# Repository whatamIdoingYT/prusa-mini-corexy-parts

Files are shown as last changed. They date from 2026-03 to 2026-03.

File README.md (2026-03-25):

# prusa-mini-corexy-parts
Additional parts for building the Prusa Mini CoreXY by SE from Printables.

The parts that you can find in this repository were designed and used by myself to build the awesome Prusa Mini CoreXY by SE from Printables. 

You can find the project here on Printables: https://www.printables.com/model/681983-prusa-mini-corexy

Make sure to check the original parts, as well as the comment section, where some people just revealed their builds and additional parts first and maybe do some measurements as well in the slicer and check the parts for errors. Maybe I've mistaken something...

For me, some parts like the X carriage shroud caused problems in the slicer, cause the walls were apparently to thin, some were to weak... Doesn't neccessarily mean, it's the same for you.

In case you have the same problems like I do, the parts attached in this repo replace the originally from SE provided parts for building the printer - those are the parts I've used for building my printer, which you can see in this video: 

You can find all the parts in the 'assets' - folder.

There is a folder called 'SpacerShims' in the 'assets' - folder. You can find various spacers and shims there. They are being used to position and hold the idlers in the Y carriages. Honestly, I forgot, which ones I've used. Just print all of them, its really just a few grams and see, what fits best for you. Maybe in the future I will do an assembly video, then I can definitely tell you, which ones I've used and in general, how the whole printer is being assembled, since there are no instructions at all. 

If I see some people interested in this project, I will do an assembly video for a basic / minimal but functional setup for a low budget of the printer.

Parts I've created / repaired / optimized are:

- X carriage (don't remember exactly what I've changed - I think I just made the middle part more stable to not crack under the pulling forces of the belts)

- fan mount for toolhead (so the fan is mounted more stable)

- X carriage shroud (original one's walls were too thin to be printed)

- front idler right (made it more rigid)

I also created some 'reinforcements' for the printer to stabilize the frame. You can see it in the video. Those parts are neccessary for one of these reinforcements:

- tower part up
- tower part down
- DiffPlate

The way the reinforcements work:

You can simply print the upper and lower part and one diff plate. The 'DiffPlate' will be layed between the upper and lower part an can be adjusted in thickness by scaling it up and down. You will want to print it in a few thicknesses to check out how thick the plate needs to be for your printer. It may vary a little bit to mine, but mine was 1.4 mm thick. By adjusting the thickness you can get the optimal support in strength for your frame. 

## **My recommended setup for you** - get yourself these parts:

- 1x 3030 extrusion 300 mm (bottom front horizontal)
- 3x 3030 extrusion 240 mm (bottom sides horizontal and one upper back horizontal)
- 2x 3030 extrusion 285 mm (bottom front vertical)
- 2x 3030 extrusion 320 mm (bottom back vertical)

- 8 idlers GT2 20 teeth 5mm bore (no teeth) for 6mm belt

- 2x around 1100mm GT2 belt 6mm (maybe just get 5m, in case you mess up some measurements and I would strongly recommend quality ones with fibreglass)

- 100 pcs of M3 x 8mm cylinder screws

You will also need to drill a 5mm hole and cut a m6 thread with a tap in the Long 320mm 3030 extrusions to mount the motors left and Right on top. At least that's how I did it and it works.

All the other parts (screws, pulleys, motors, rods, fans...) are being reused from your Prusa Mini / Mini +, so disassemble it carefully. Read trhough the project on Printables carefully. Maybe a few times. Look at all the parts in the project. I can recommend to print a lot of the 'ALU 90' ninety degree connector parts to connect every 3030 extrusion from every side you can with the other 3030 extrusions, to make the frame really rigid. It will be! You can use the 'ALU nut M3' for it as well, to secure them on the 3030 extrusions. They work fine. Make sure to maybe scale them a little bit smaller, because they can be quite hard to be inserted into the extrusions otherwise - just print one in 100 percent scale and check, if adjustments are needed for you.

Feel free to ask questions. I will try to answer them - either here, or on Printables. On Printables you will probably get more support, because it's the projects origin :)

## My personal printer config for OrcaSlicer with profiles for ESUN PETG HS and PLA+

**Important Note:** This configuration is specifically tuned for a setup with a **Bondtech bowden extruder** and a **titanium heatbreak**. If you are running a stock setup, please make sure to adjust or remove the custom E-steps (`M92`) and PID tuning values (`M301`) in the Start G-Code! I am also using a Bondtech 0.4 CHT Nozzle, so I am able to extrude a lot more filament withthe stock hotend - around twice as much as with a stock nozzle. Another thing to watch out for is the build plate position! My build plate has a space of 36mm to the left horizontal 3030 extrusion and 14mm to the right horizontal 3030 extrusion (measured from the edge of the original smooth build plate to the inner edge of the extrusions where the Y carriages are running above - horizontally measured). The flow values, as well as the pressure advance values may vary for your type of filament. I tested them for the 0.4 CHT nozzle from Bondtech and the specific filaments.

You can download my OrcaSlicer configuration from the 'printer configuration' folder. I mainly use the printer for ESUN PETG HS and for that the configuration works just fine! The ESUN PLA+ configuration also worked fine as far as I remember. Haven't been printing it for a while. The Benchy configuration should be a pretty fast speed one which I can not recommend to run. The cooling can not keep up with the printing speed. Otherwise the results weren't even that bad :) Maybe with a different duct (maybe the one from the Printables comment section) will lead to better results - looking forward for testing it!

Just download it, mess around with it and tweak it for your personal preferences! Maybe its just a good starting point for you, if you like :) Or just create your own configuration from scratch. Using the Bambu A1 Mini configuration to configurate the Prusa Mini CoreXY was the way to go for me!

## Input Shaping

I've set my input shaping values as the following for the Mini CoreXY, based on my testing,**but the Values may vary for you:**

**Filter:**

**MVZ** on **both axes**

**Frequencies:**

**37** on the **X - axis**

**40** on the **Y - axis**

## StealthChop (aka make my printer scream for dear life)

If you are not using my OrcaSlicer printer configuration and you want to print above certain speeds (probably around 75 mm/s upwards), your printer will eventually start to scream! To prevent it from doing that, turn off StealthChop on all axis with this command:

```gcode
M569 S0 X Y Z;
```
Disable directly AFTER the homing routine! It needs it for homing! Otherwise the toolhead may crash and will kill your belt by running into the Y carriage (don't ask me how I know...).
StealthChop is  being used to make your printer more silent - which apparently doesn't seem to work for this modified version of the Prusa Mini. So turn it off and use SpreadCycle instead. It's not worse - it's actually performing better. It is more noisy though compared to StealthChop (under normal circumstances), but in this case it will make your printer not scream beyond speeds of around 75 mm/s... so take the little bit more noise :)

## **Disclaimer and Limitation of Liability**

**Please read this disclaimer carefully before using, modifying, or building upon this open-source project.**

By accessing, downloading, or using the files, instructions, and information provided in this project, you agree to the following terms:

* **Assumption of Risk ("Do It At Your Own Risk"):** Building, modifying, and operating 3D printers involves **inherent risks**. You will be working with **high-voltage electricity**, **high temperatures** (hotends, heated beds), and **moving mechanical parts**. You acknowledge that you are undertaking this project **entirely at your own risk**. It is your responsibility to ensure you have the necessary skills, knowledge, and safety precautions in place before starting.

* **"As Is" Content / No Warranty:** All files, code, models, and documentation are provided **"AS IS"**, without warranty of any kind, express or implied. The creator makes **no guarantees** regarding the safety, reliability, accuracy, or suitability of this project for any specific purpose.

* **Limitation of Liability:** Under **no circumstances** shall the creator(s), contributors, or maintainers of this project be held liable for any direct, indirect, incidental, special, or consequential damages. This includes, but is **not limited to**:
    * **Personal injury or death**
    * **Property damage** (including **fire** caused by thermal runaway or electrical faults)
    * **Damage to your 3D printer** or other equipment
    * **Loss of time, materials, or profits**
    arising out of the use, inability to use, or modifications made to this project.

* **Safety Warning:** Always follow basic electrical and fire safety guidelines. **Never leave a modified or DIY 3D printer running unattended** unless you have thoroughly tested all safety features (such as thermal runaway protection, proper grounding, and appropriate wire gauges). You are **solely responsible** for ensuring your build complies with local safety regulations and standards.

**By using this project, you accept full responsibility for your actions and any outcomes that may result.**

## Acknowledgements / Credits

This project is a remix of / based on:
* **"Prusa MINI coreXY"** by SE. 
    * Source: (https://www.printables.com/model/681983-prusa-mini-corexy)
    * License: [CC BY-SA 4.0](https://creativecommons.org/licenses/by-sa/4.0/)

## License

In accordance with the ShareAlike condition of the original project and to support the open-source community, this entire project (including the newly added parts I designed) is also released under the **Creative Commons Attribution-ShareAlike 4.0 International (CC BY-SA 4.0)** license.

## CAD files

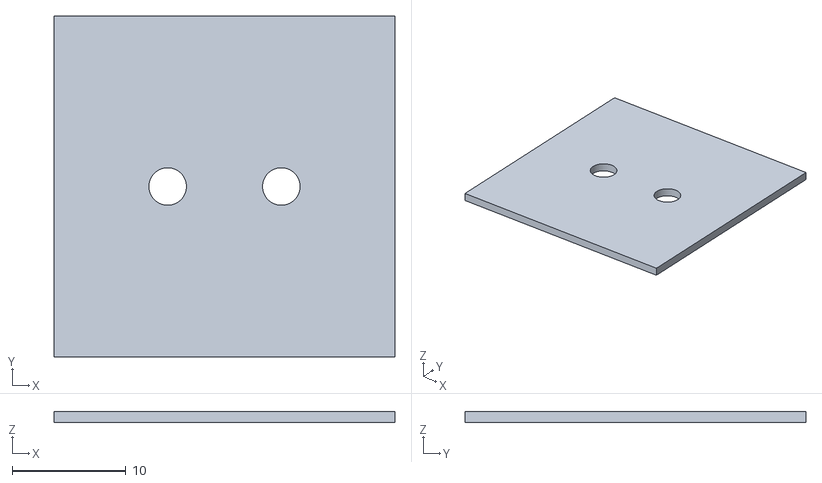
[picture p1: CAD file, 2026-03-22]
assets/DiffPlate.stl
30.0 x 30.0 x 1.00

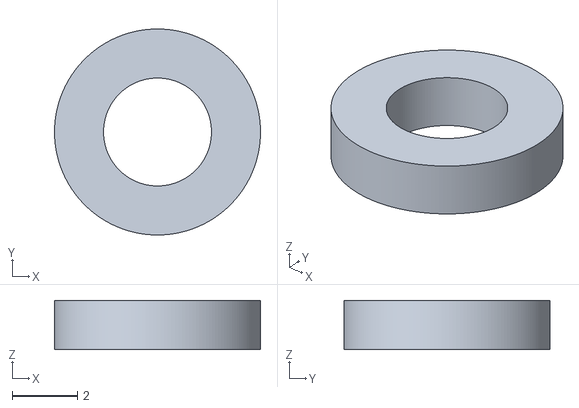
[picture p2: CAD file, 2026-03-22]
assets/SpacerShims/SpacerIdlerMount.stl
6.30 x 6.30 x 1.50

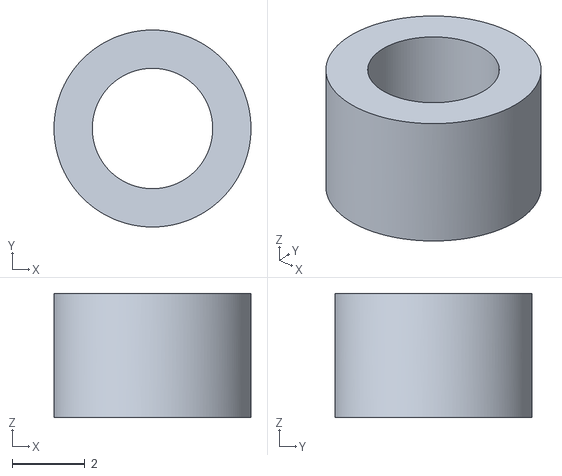
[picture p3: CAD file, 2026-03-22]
assets/SpacerShims/SpacerMotorIdlers.stl
5.40 x 5.40 x 3.40

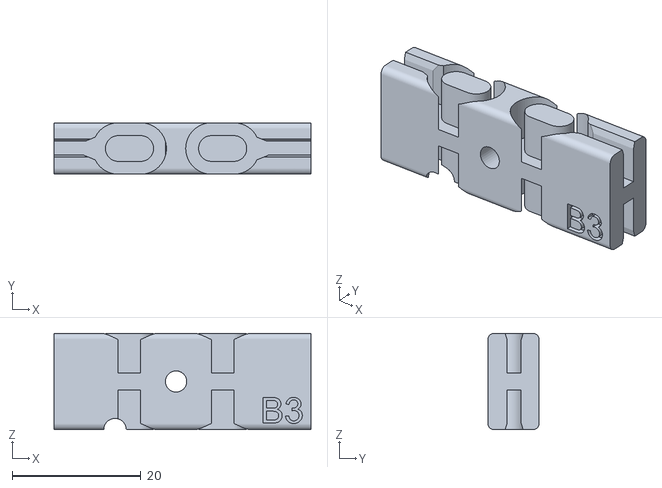
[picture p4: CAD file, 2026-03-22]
assets/X Carriage repaired.stl
40.0 x 8.00 x 15.0

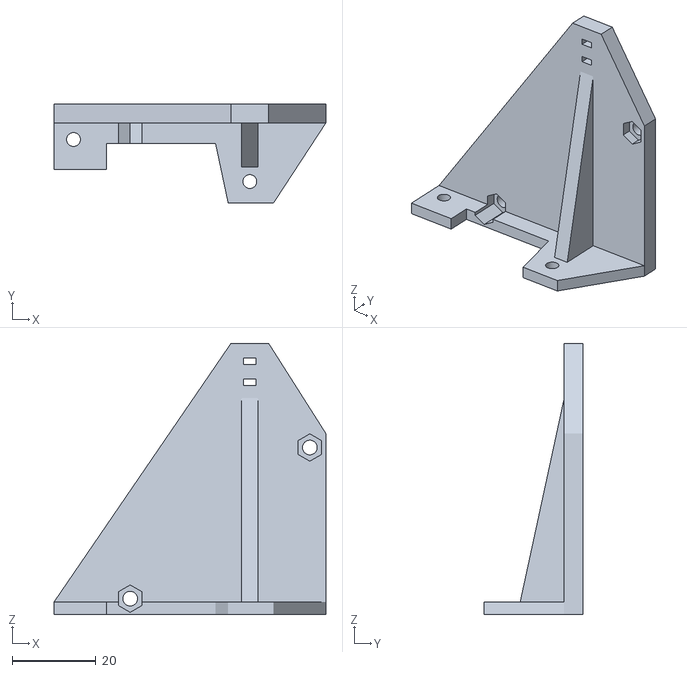
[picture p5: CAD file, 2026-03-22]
assets/FanMount.stl
64.8 x 23.7 x 64.6

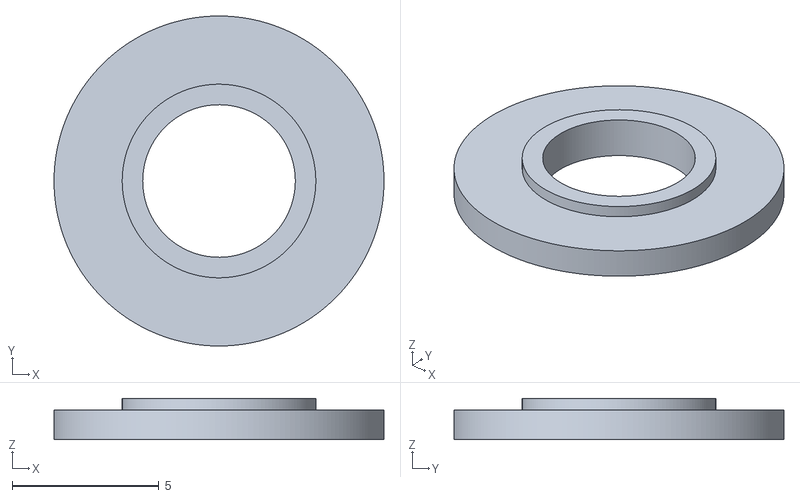
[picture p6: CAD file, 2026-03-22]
assets/SpacerShims/Shim014.stl
11.2 x 11.2 x 1.40

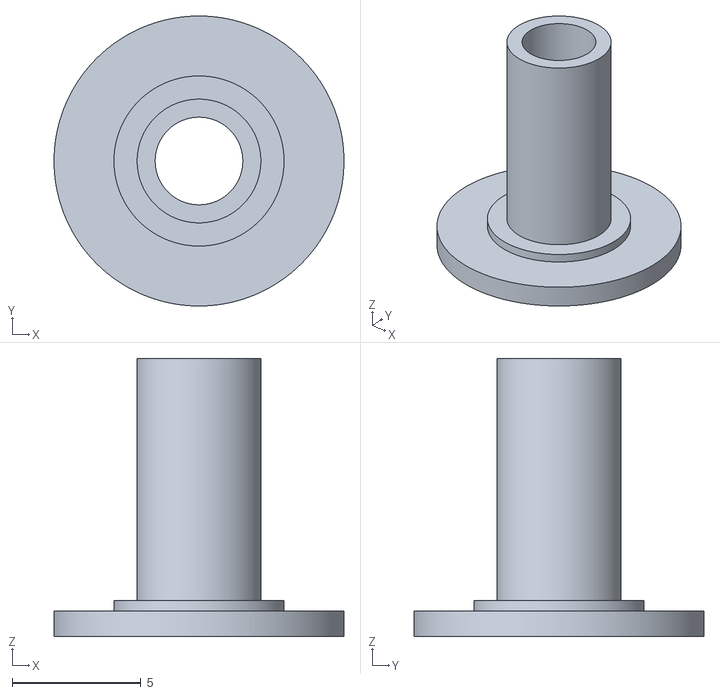
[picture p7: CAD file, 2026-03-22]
assets/SpacerShims/Spacer108.stl
11.2 x 11.2 x 10.8

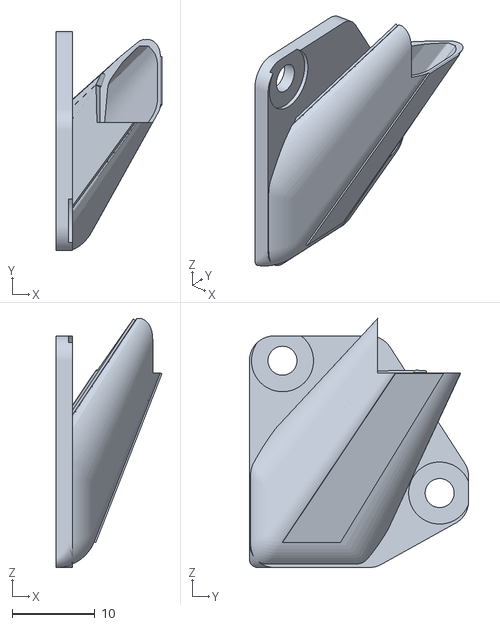
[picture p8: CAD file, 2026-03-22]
assets/X carriage shroud.stl
12.8 x 26.5 x 30.1

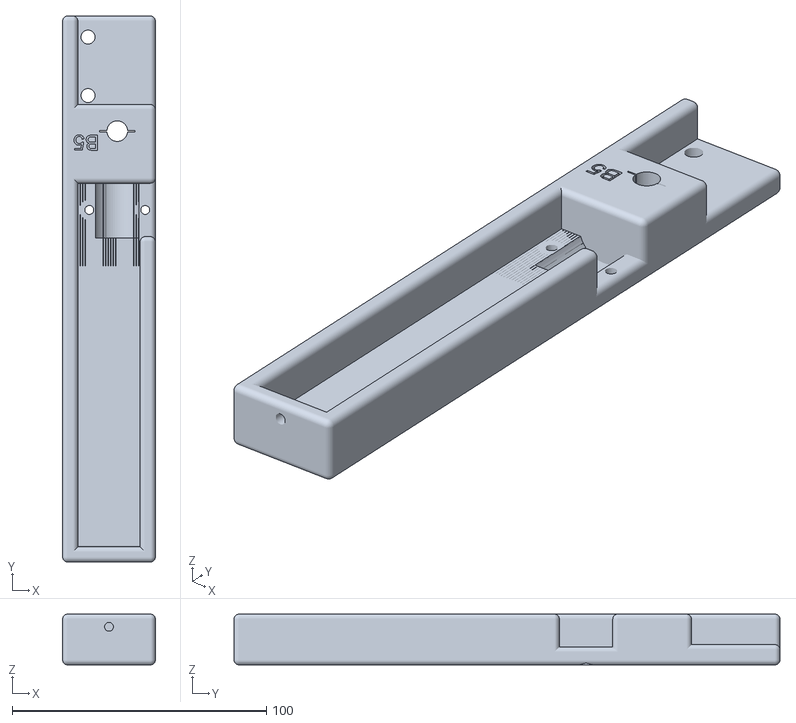
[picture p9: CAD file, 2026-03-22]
assets/IdlerRightFixed.stl
36.5 x 214.8 x 20.0

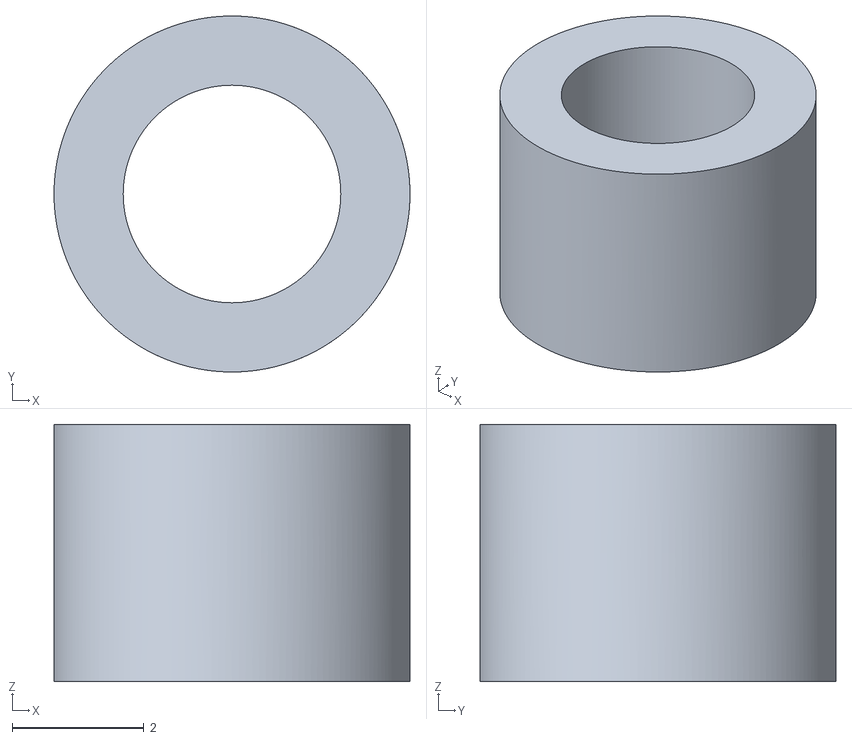
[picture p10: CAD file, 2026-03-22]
assets/SpacerShims/SpacerMotorIdlerSizedUp.stl
5.40 x 5.40 x 3.90

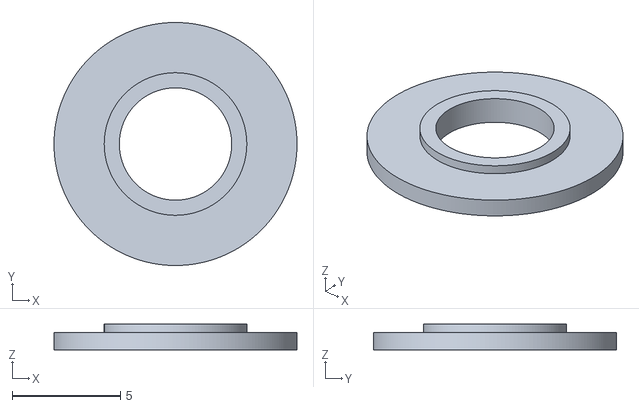
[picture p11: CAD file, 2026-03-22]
assets/SpacerShims/Shim12.stl
11.2 x 11.2 x 1.20

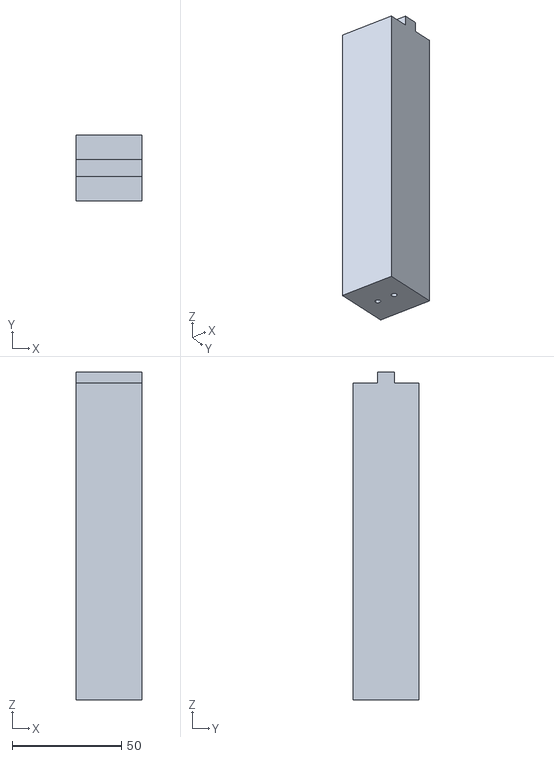
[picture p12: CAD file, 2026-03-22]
assets/TowerPartDown.stl
30.0 x 30.0 x 150.0

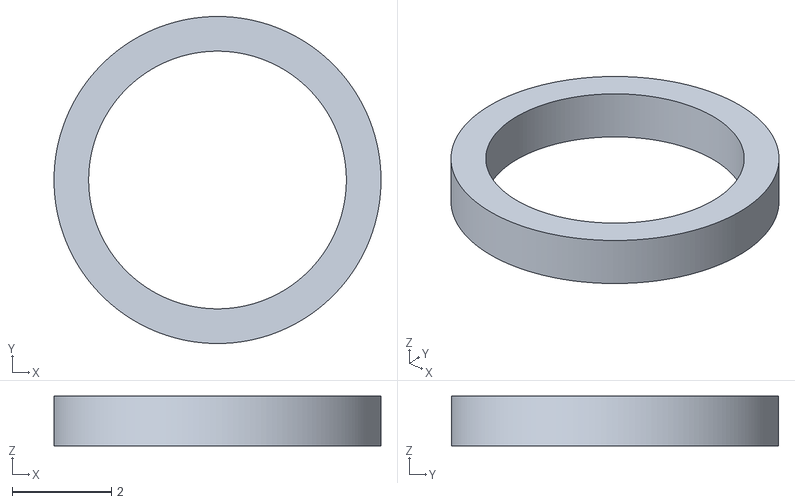
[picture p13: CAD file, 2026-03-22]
assets/SpacerShims/Shim010.stl
6.60 x 6.60 x 1.00

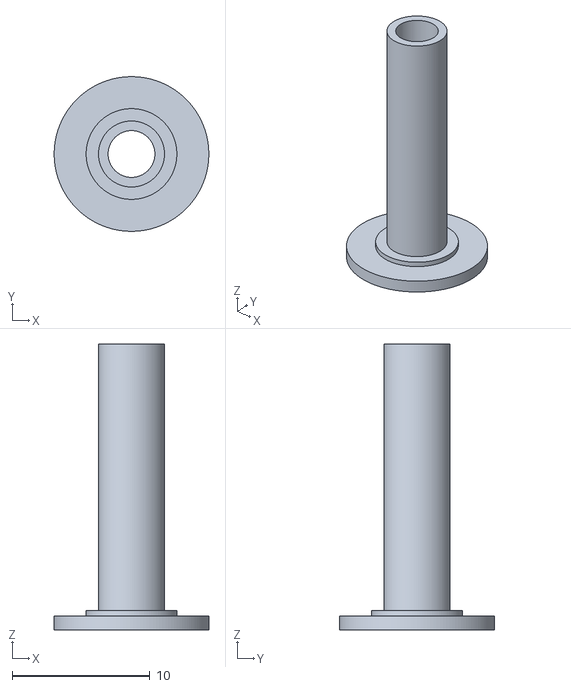
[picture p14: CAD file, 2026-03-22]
assets/SpacerShims/Spacer208.stl
11.2 x 11.2 x 20.8

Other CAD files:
assets/TowerPartUp.stl
assets/SpacerShims/Spacer106.stl

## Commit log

2026-03-22 Create SpacerShims folder
2026-03-22 Added parts in assets folder
    [DiffPlate.stl, FanMount.stl, IdlerRightFixed.stl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]
2026-03-22 Added spacers and shims to folder
    [Shim010.stl, Shim014.stl, Shim12.stl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]
